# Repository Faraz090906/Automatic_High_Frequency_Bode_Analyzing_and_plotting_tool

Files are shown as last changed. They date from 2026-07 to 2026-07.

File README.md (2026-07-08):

# 📈 Automatic High-Frequency Bode Analyzer & Plotter (AHFBAAPT)

**A standalone, embedded Bode plotter for ~₹8,000 — no PC, no software, just power and a DUT.**

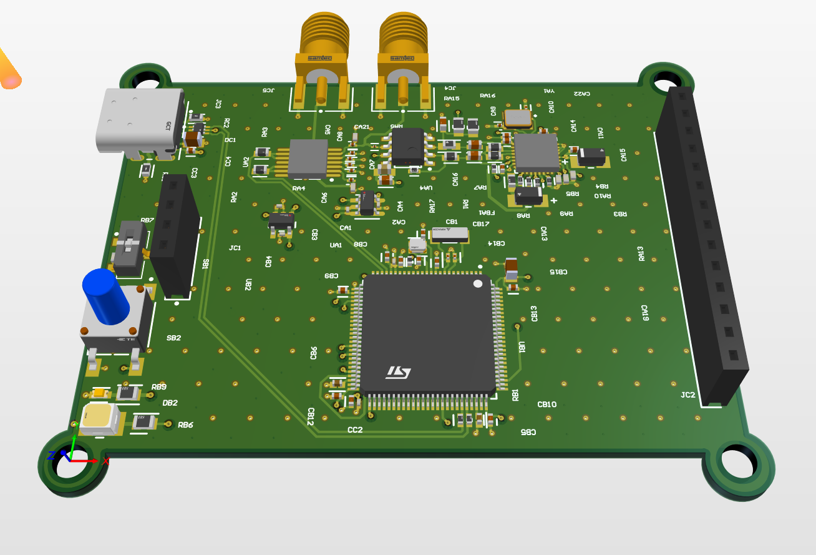
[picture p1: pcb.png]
Bode Plotter PCB








---

## 🔎 Overview

Frequency response analysis usually means choosing between a lab-grade VNA (₹20k–₹2L), a bench scope + signal generator setup (slow and manual), or a PC-tethered NanoVNA. **AHFBAAPT** is a self-contained alternative: a hand-solderable, USB-C powered PCB that sweeps a signal through a device under test (DUT), measures magnitude and phase in real time, displays the result on an onboard touchscreen, and logs everything to a microSD card as CSV — with no computer required.

It's aimed at embedded engineers doing hardware bring-up, university labs teaching signals/RF courses, and hobbyists characterizing filters, inductors, and antenna matching networks.

## ✨ Key Features

- 📡 **Wide sweep range** — 10mHz to 100MHz, with 0.058Hz frequency resolution (32-bit tuning word)
- 🎯 **Accurate measurement** — ±30dB magnitude (±0.5dB accuracy) and 0°–180° phase (±1° accuracy)
- 🔢 **Up to 4096 log-spaced sweep points** per run
- 🔌 **Standalone operation** — no PC or companion software needed
- 🖥️ **2.4" touchscreen TFT** for real-time plotting and read-off of frequency/gain/phase at any point
- 💾 **microSD logging** — sweep results exported as CSV
- ⚡ **USB-C powered** (~300mA) and **USB-C data** for streaming/firmware updates
- 🛠️ **Open firmware** — full STM32 HAL access, easily extended (custom sweep profiles, Wi-Fi, USB streaming)
- 🧩 **Hand-solderable** 4-layer PCB build

## ⚙️ How It Works

The signal chain is a simple stimulus → measure → process pipeline:

1. **Stimulus** — The `AD9913` DDS synthesizer generates a swept sine wave from `f_start` to `f_stop` in log-spaced steps, driven by a 32-bit frequency tuning word.
2. **Measurement** — The `AD8302` gain/phase detector compares the DUT's output against the input and outputs two calibrated DC voltages: `VMAG` (30mV/dB) and `VPHS` (10mV/°).
3. **Processing** — The `STM32H750` reads both channels through its 12-bit ADC with 64× oversampling, converts the readings to dB/° (0.027dB/LSB), and updates the display and log in real time.

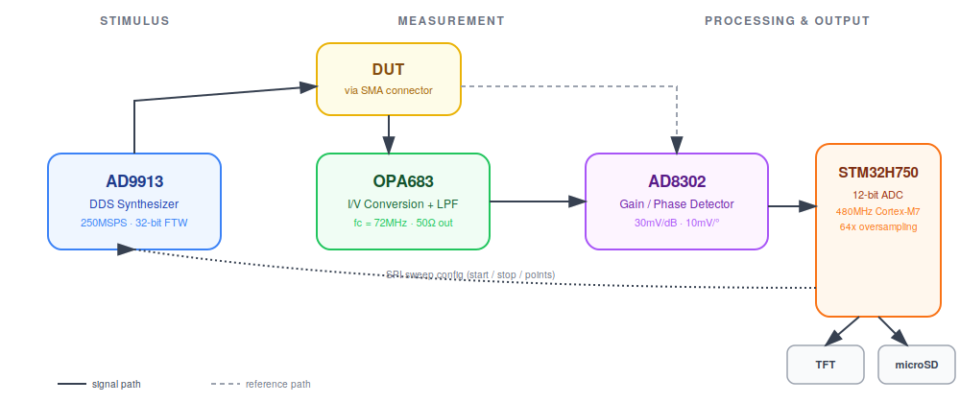
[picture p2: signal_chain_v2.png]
Signal Chain Diagram


## 📊 System Specifications

| Parameter | Value |
|---|---|
| Frequency range | 10mHz – 100MHz |
| Frequency resolution | 0.058Hz (32-bit FTW) |
| Magnitude range | ±30dB (60dB total) |
| Magnitude accuracy | ±0.5dB |
| Phase range | 0° – 180° |
| Phase accuracy | ±1° |
| Sweep points | Up to 4096 (log-spaced) |
| Input impedance | 50Ω (SMA) |
| Display | 2.4" TFT, touch (ILI9341) |
| Storage | microSD, CSV export |
| Connectivity | USB-C (power + full-speed data) |
| Power | USB-C +5V, ~300mA |
| PCB | 4-layer, hand-solderable |

## 🧠 Key Components

| Chip | Role | Highlights |
|---|---|---|
| **AD9913BCPZ** | DDS Synthesizer | 250MSPS, 32-bit FTW, 10mHz–100MHz output, built-in linear sweep, SPI interface |
| **AD8302ARUZ** | Gain/Phase Detector | DC–2.7GHz input, ±30dB magnitude, 0°–180° phase, 30mV/dB & 10mV/°, single 5V supply |
| **OPA683ID** | High-Speed Op-Amp | I/V conversion (TIA), 72MHz low-pass filter, 50Ω output conditioning |
| **STM32H750VBT6** | MCU | 480MHz Cortex-M7, 12-bit ADC (64× oversample), 4× SPI (DDS/TFT/SD/touch), USB-C |

## 🔋 Power Architecture

Two regulated rails are derived from the USB-C +5V input:

- **TLV75533 → 3.3V digital** — powers the STM32, TFT, SD card, and USB
- **TLV75518 → 1.8V analog** — powers the AD9913 and AD8302
- A ferrite bead isolates the analog supply (VDDA) for a clean ADC reference, with separate ground pour planes and a star-point GND to keep digital switching noise off the analog rail

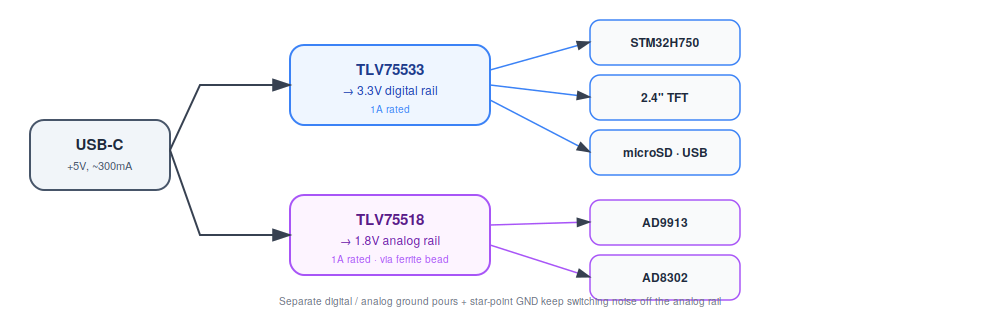
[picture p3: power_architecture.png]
Power Architecture Diagram


## 💰 Cost Breakdown (single unit, approx.)

| Item | Cost (₹) |
|---|---|
| STM32H750VBT6 | 665.71 |
| AD9913BCPZ (DDS) | 2,722.15 |
| AD8302ARUZ | 3,112.06 |
| OPA683ID | 468.96 |
| 2.4" TFT + ILI9341 | 500 |
| LDOs, passives, connectors | ≈500 |
| Crystal, etc. | 300 |
| **Total (all-in)** | **~₹8,270** |

For comparison, a comparable lab-grade VNA costs ₹20,000 – ₹13,00,000.

## 📁 Repository Contents

```
.
├── README.md                     # This file
├── pcb.png                       # Rendered/photographed PCB
├── diagrams/                     # Illustrative diagrams used in this README
│   ├── signal_chain_v2.png
│   └── power_architecture.png
├── pitch.pdf                     # Project pitch deck (problem, use cases, USPs, roadmap)
├── Report.pdf                    # One-page technical summary / spec sheet
├── Schematic.pdf                 # Exported schematic
└── bode_plotter_project.zip      # Full Altium Designer project
    └── Automatic High Frequency Bode Analysing and Plotting Tool (AHFBAAPT)/
        ├── *.PrjPcb, *.PrjPcbStructure   # Altium project files
        ├── schematic_A.SchDoc            # Schematics (split across A/B/C sheets)
        ├── schematic_B.SchDoc
        ├── schematic_C.SchDoc
        ├── PCB1.PcbDoc                    # PCB layout
        ├── *.OutJob                       # Output job configurations (Gerbers, BOM, etc.)
        ├── *.BomDoc                       # Bill of materials
        └── CAMtastic*.Cam                 # CAM/Gerber outputs
```

> **Note:** The hardware design lives entirely in [Altium Designer](https://www.altium.com/) project files (`.PrjPcb`, `.SchDoc`, `.PcbDoc`). You'll need Altium Designer (or Altium 365 viewer) to open and edit them.

## 🚀 Getting Started

### Viewing the Design
1. Download and extract `bode_plotter_project.zip`.
2. Open `Automatic High Frequency Bode Analysing and Plotting Tool (AHFBAAPT).PrjPcb` in Altium Designer to browse schematics and PCB layout.
3. Alternatively, view `Schematic.pdf` and `Report.pdf` directly for a quick look without any EDA tool installed.

### Manufacturing
- Generate Gerbers/CAM outputs via the included `.OutJob` files, or use the pre-generated `CAMtastic*.Cam` files.
- The BOM is available in the `.BomDoc` file inside the project folder.
- Board is a 4-layer design intended to be hand-solderable.

### Powering & Operating (once assembled)
1. Connect the DUT to the SMA input.
2. Power the board via USB-C (+5V, ~300mA).
3. Configure the sweep (start/stop frequency, number of points) via the touchscreen.
4. View magnitude/phase in real time on the 2.4" TFT, and optionally log results to microSD as CSV.

## 👥 Who Is This For?

- **Embedded engineers** — test filters and amplifiers during hardware bring-up without leaving the bench
- **University labs** — an affordable, student-buildable teaching tool for signals/RF courses
- **RF hobbyists** — characterize hand-wound inductors, ceramic filters, and antenna matching networks

## 🗺️ Roadmap

- **Rev 1.0 (current)** — AD9913 + AD8302 + STM32H750, 2.4" TFT, SD card, USB-C. 10mHz–100MHz, ±30dB, ±1°. ~₹8k all-in.
- **Rev 2.0 (near term)** — Full DUT analysis, extend frequency range up to 1GHz, extend gain range to ±50–60dB. Each revision aims to remain hand-solderable and under ₹10,000 built.

## 🧑‍💻 Authors

- Akshara Sarma Chennubhatla — EE24BTECH11003
- Patnam Shariq Faraz Muhammed — EE24BTECH11049
- Siddhanth Yellanki — EE24BTECH11059

## 📜 License

No license file is currently included in this repository. If you intend to reuse or build on this design, please reach out to the authors to clarify usage terms.

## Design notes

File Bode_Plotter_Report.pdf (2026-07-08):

High-Frequency Bode Plotter
10 mHz–100 MHz • ±30 dB Magnitude • ±1° Phase • Standalone • No PC • Open

Firmware

Akshara Sarma Chennubhatla Patnam Shariq Faraz Muhammed Siddanth Yellanki
EE24BTECH11003 / EE24BTECH11049 / EE24BTECH11059

### 1. Deliverables

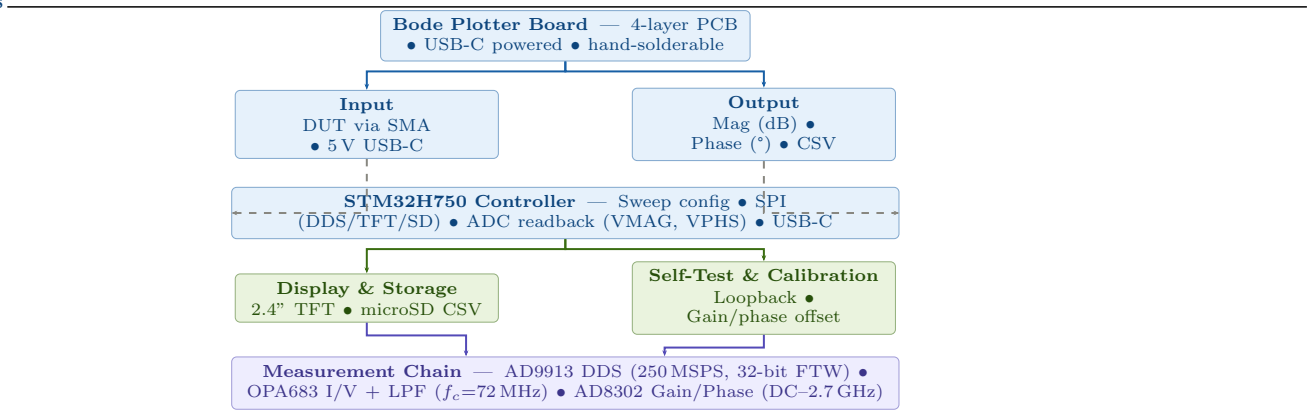
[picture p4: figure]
Bode Plotter Board — 4-layer PCB • USB-C powered • hand-solderable; Input DUT via SMA • 5 V USB-C; Output Mag (dB) • Phase (°) • CSV; Display & Storage 2.4” TFT • microSD CSV; Self-Test & Calibration Loopback •; Gain/phase offset

STM32H750 Controller — Sweep config • SPI (DDS/TFT/SD) • ADC readback (VMAG, VPHS) • USB-C

Measurement Chain — AD9913 DDS (250 MSPS, 32-bit FTW) • OPA683 I/V + LPF (fc=72 MHz) • AD8302 Gain/Phase (DC–2.7 GHz)

### 2. System Specifications

Frequency Range

### 10 mHz – 100 MHz • 0.058 Hz resolution (32-bit FTW) • Up

to 4096 log-spaced sweep points

Magnitude & Phase
Magnitude: ±30 dB range, ±0.5 dB accuracy (30 mV/dB) Phase: 0°–180°, ±1° accuracy (10 mV/°)

Signal Source & ADC
AD9913 DDS, 250 MSPS, 25 MHz TCXO reference STM32H750 480 MHz M7 • 12-bit ADC • 64× oversample • 0.027 dB/LSB

Power
USB-C +5 V, ∼300 mA • 3.3 V digital (TLV75533) • 1.8 V analog (TLV75518) • Ferrite-bead isolated rails

### 4. Interfaces

SPI Bus
AD9913 config • 2.4” TFT (ILI9341) • microSD • touch controller

Analog RF & ADC
IOUT/IOUTB diff. out, 50 Ω DUT port, REF tap to AD8302 VMAG: 30 mV/dB • VPHS: 10 mV/°• RC filter fc=159 Hz

USB-C
Full-speed USB • Power + data • Future: live streaming

### 5. Performance

Key Features
- Fully standalone — no PC, no software
- 4096-point log sweep, touch readout of freq/gain/phase
- Real-time Bode plot on 2.4” TFT display
- microSD CSV export, open STM32 HAL firmware

### 3. Key ICs

AD9913 — DDS Synthesiser
250 MSPS • 10 mHz–100 MHz output • 32-bit FTW (0.058 Hz res.) • Built-in linear sweep • SPI interface

AD8302 — Gain/Phase Detector
DC to 2.7 GHz • ±30 dB magnitude range • 0°–180° phase range
- 30 mV/dB • 10 mV/°• Single 5 V supply

OPA683 — High-Speed Op-Amp
I/V conversion (TIA config) • fc = 72 MHz LPF • 50 Ω output conditioning

STM32H750VBT6 — MCU
480 MHz Cortex-M7 • SPI ×4 (DDS/TFT/SD/touch) • USB-C Full Speed • LQFP-100, hand-solderable

TLV75518 / TLV75533 — LDOs
1.8 V analog rail + 3.3 V digital rail • 1 A rated • Separate pour planes.

### 6. Cost Breakdown

Item | INR
PCB Fabrication | 2,400

PCB Assembly

2,680

Components / BoM | 9,949
Total | 15,029

Further details: Bode Plotter (https://drive.google.com/drive/folders/1nUOeqKWaKO9xSWlELa47L8NvQM5F9w_Q)

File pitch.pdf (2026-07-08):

# Bode Plotter PCB

## Swept Frequency Analyser · 10 mHz to 100 MHz

## 10 mHz

to 100 MHz

±30 dB

Magnitude

±1°

Phase accuracy

˜|8k

All-in cost

EE24BTECH11003: Akshara Sarma · EE24BTECH11049: Faraz P · EE24BTECH11059: Siddhanth

AD9913 DDS · AD8302 · STM32H750VBT6 · March 2026

## The Problem

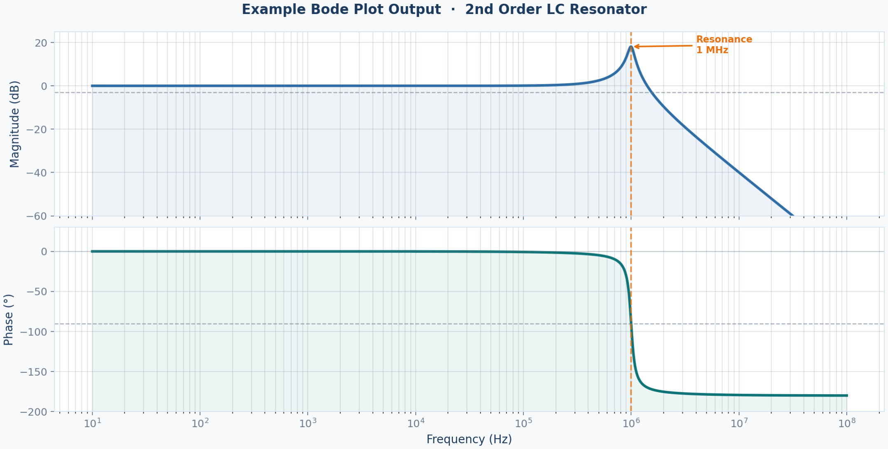
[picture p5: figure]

## Engineers need frequency

response data.

Today’s options:
- Lab VNA — accurate but |20k -|2 Lakhs
- Bench scope + sig gen — slow, manual, error-prone
- NanoVNA — cheap but
PC-tethered, limited range

None are self-contained, affordable & embedded.

USE CASE

A standalone,

# embedded Bode plotter

for |8k.

## Sweep 10 mHz to 100 MHz. Read

magnitude and phase on a 2.4 inch display.

## Log results to SD card. No PC. No

software. Just power and a DUT.

Self-contained

No PC needed

Open firmware

Full STM32 control

Logs to SD

CSV export

˜|8k built

4-layer PCB

## Who Is It For

Embedded Engineers

Test filters and amplifiers during hardware bring-up
without leaving the bench.

University Labs

Affordable teaching tool
for circuits and signals
courses.
Student-buildable.

RF Hobbyists

Characterise hand-wound
inductors, ceramic filters, antenna matching
networks.

## Anyone who needs frequency response data and doesn’t want to

spend |50000 on a VNA.

USE CASE

## How It Works

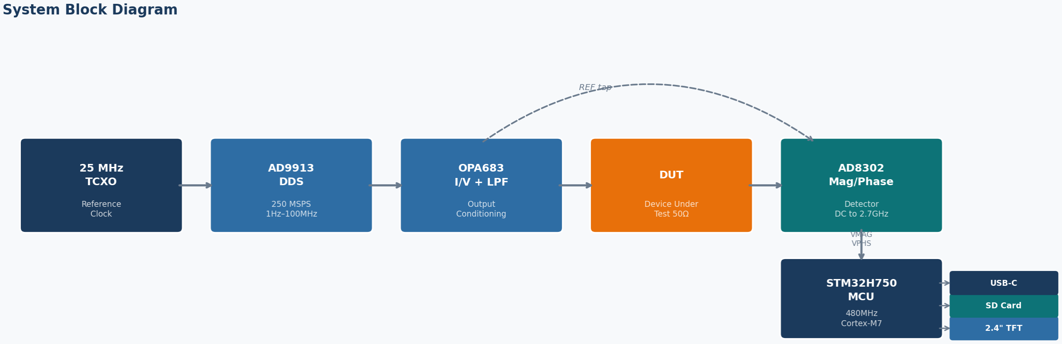
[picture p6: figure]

DDS generates swept sine · AD8302 measures ratio of output to input · STM32 reads two DC voltages and plots the result in real time

HOW IT WORKS

## Signal Chain

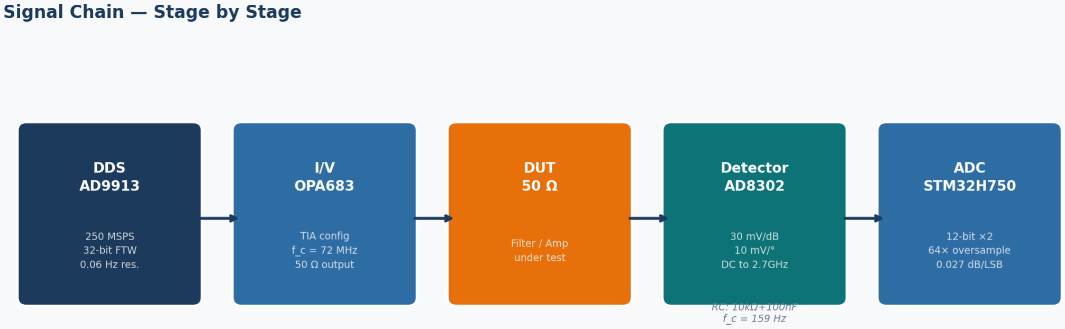
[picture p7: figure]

Stimulus
AD9913 DDS sweeps

from fstart to fstop in
log-spaced steps. 32-bit
tuning word: 0.058 Hz
resolution.

Measurement
AD8302 outputs two
calibrated DC voltages:
VMAG (30 mV/dB) and
VPHS (10 mV/°).

Processing
STM32 ADC reads both
channels with 64x
oversampling, converts to
dB/°, updates the display.

HOW IT WORKS

AD9913

DDS Synthesiser

- 250 MSPS system
clock
- 10 mHz to 100 MHz
output
- 32-bit frequency word
- Built-in linear sweep
mode
- SPI interface

AD8302

Gain/Phase Detector

- DC to 2.7 GHz input
range
- ±30 dB magnitude
range
- 0° to 180° phase
range
- 30 mV/dB · 10 mV/°
output
- Single supply, 5 V

## STM32H750

MCU & Controller

- 480 MHz Cortex-M7
- 12-bit ADC, 64×
oversample
- SPI × 4: DDS, TFT,
SD, touch
- USB-C full speed
- LQFP-100,
hand-solderable

Three chips do all the work.

## Power Architecture

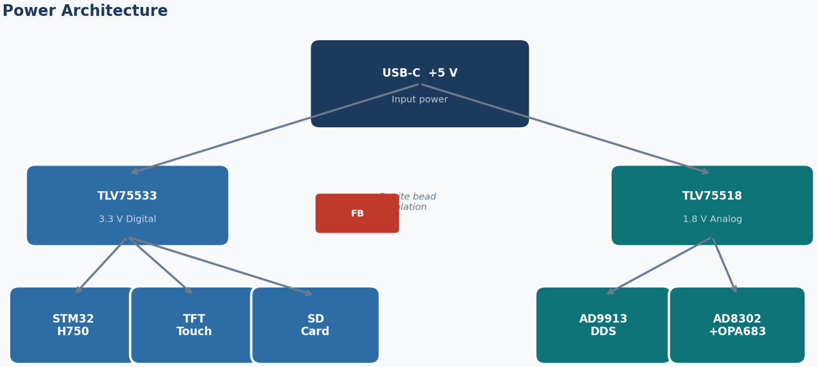
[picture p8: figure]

Both LDOs rated 1 A. Total system current: ˜300 mA at full speed. Powered from any USB-C source.

Two rails from USB-C +5 V:

- TLV75533 → 3.3 V digital

STM32, TFT, SD card, USB

- TLV75518 → 1.8 V analog

AD9913, AD8302

- Ferrite bead isolates VDDA Clean ADC reference, no digital noise on analog rail
- 1.8 V split: analog vs. digital Separate pour planes, star-point GND
HOW IT WORKS

## Unique Selling Points

No PC required
Full sweep, display and SD logging run on the STM32. Results appear on the 2.4 in TFT in real time. Touch screen lets you read off frequency, gain and phase at any point.

Open firmware
STM32H750 | with | full | HAL | access.
Change sweep range, point count, settle time, add USB streaming, add Wi-Fi module — all in C.

### 10 mHz floor

AD9913 32-bit FTW gives 0.06 Hz resolution. Most comparable tools start at 50 kHz or higher.

USP

## Cost Breakdown

Item | Cost
STM32H750VBT6 | |665.71
AD9913BCPZ (DDS) | |2,722.15
AD8302ARUZ | |3,112.06
OPA683ID | |468.96
2.4” TFT + ILI9341 | |500
LDOs, passives, connectors | ≈ |500
crystal, etc. | |300
All-in (single unit) | ˜|8,270

Comparable lab VNA: |20k - 13L This instrument: |8k
COST

## Specifications at a glance

Parameter | Value | Feature | Detail
Frequency range | 10 mHz – 100 MHz | Display | 2.4” TFT, touch
Magnitude range | ±30 dB (60 dB total) | Storage | microSD, CSV
Phase range | 0° – 180° | USB | USB-C Full Speed
Mag. accuracy | ±0.5 dB | Power | USB-C +5 V
Phase accuracy | ±1° | MCU | STM32H750, 480 MHz
Freq. resolution | 0.058 Hz | DDS | AD9913, 250 MSPS
Sweep points | Up to 4096 | Detector | AD8302, DC–2.7 GHz
Input impedance | 50 Ω | Build | Hand-solderable

## Roadmap

Rev 1.0 — Now

AD9913 + AD8302 + STM32H750 2.4” TFT · SD card · USB-C 10 mHz–100 MHz · ±30 dB · ±1°

|8k all-in

Rev 2.0 — Near Term

Provide complete DUT analysis Increase freq range upto 1GHz Increase gain range upto ± 50dB-60dB

Each revision remains hand-solderable and under |10000 built.

NEXT STEPS

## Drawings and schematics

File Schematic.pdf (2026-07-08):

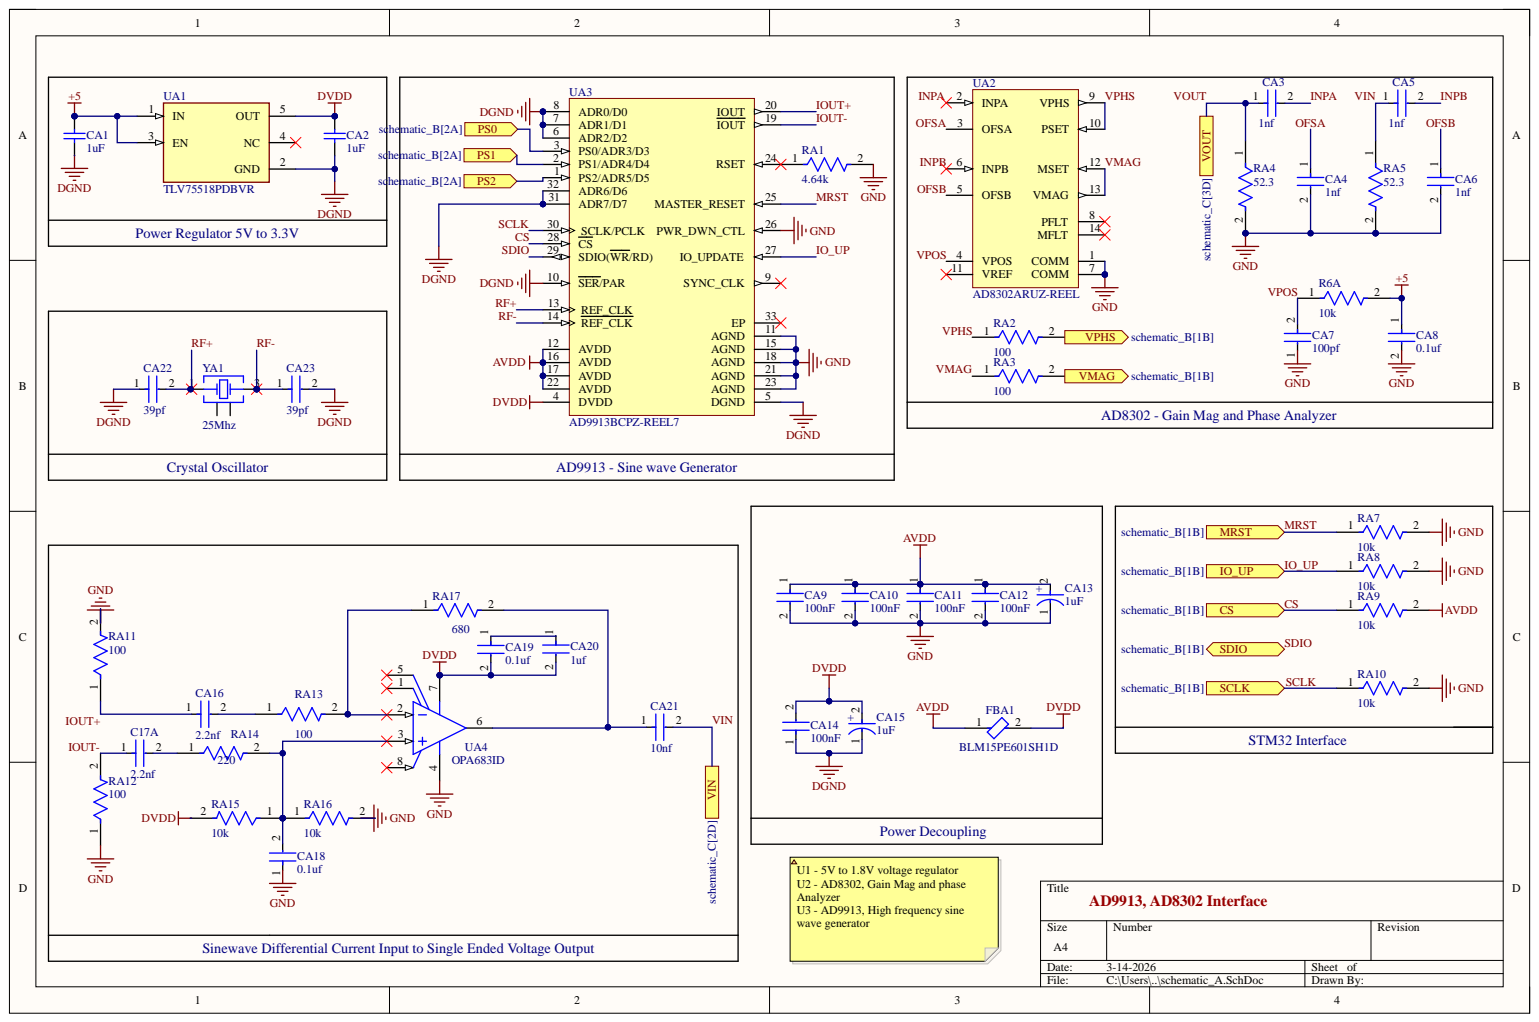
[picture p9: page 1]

AD8302 - Gain Mag and Phase Analyzer

U1 - 5V to 1.8V voltage regulator
U2 - AD8302, Gain Mag and phase
Analyzer
U3 - AD9913, High frequency sine
wave generator

Sinewave Differential Current Input to Single Ended Voltage Output

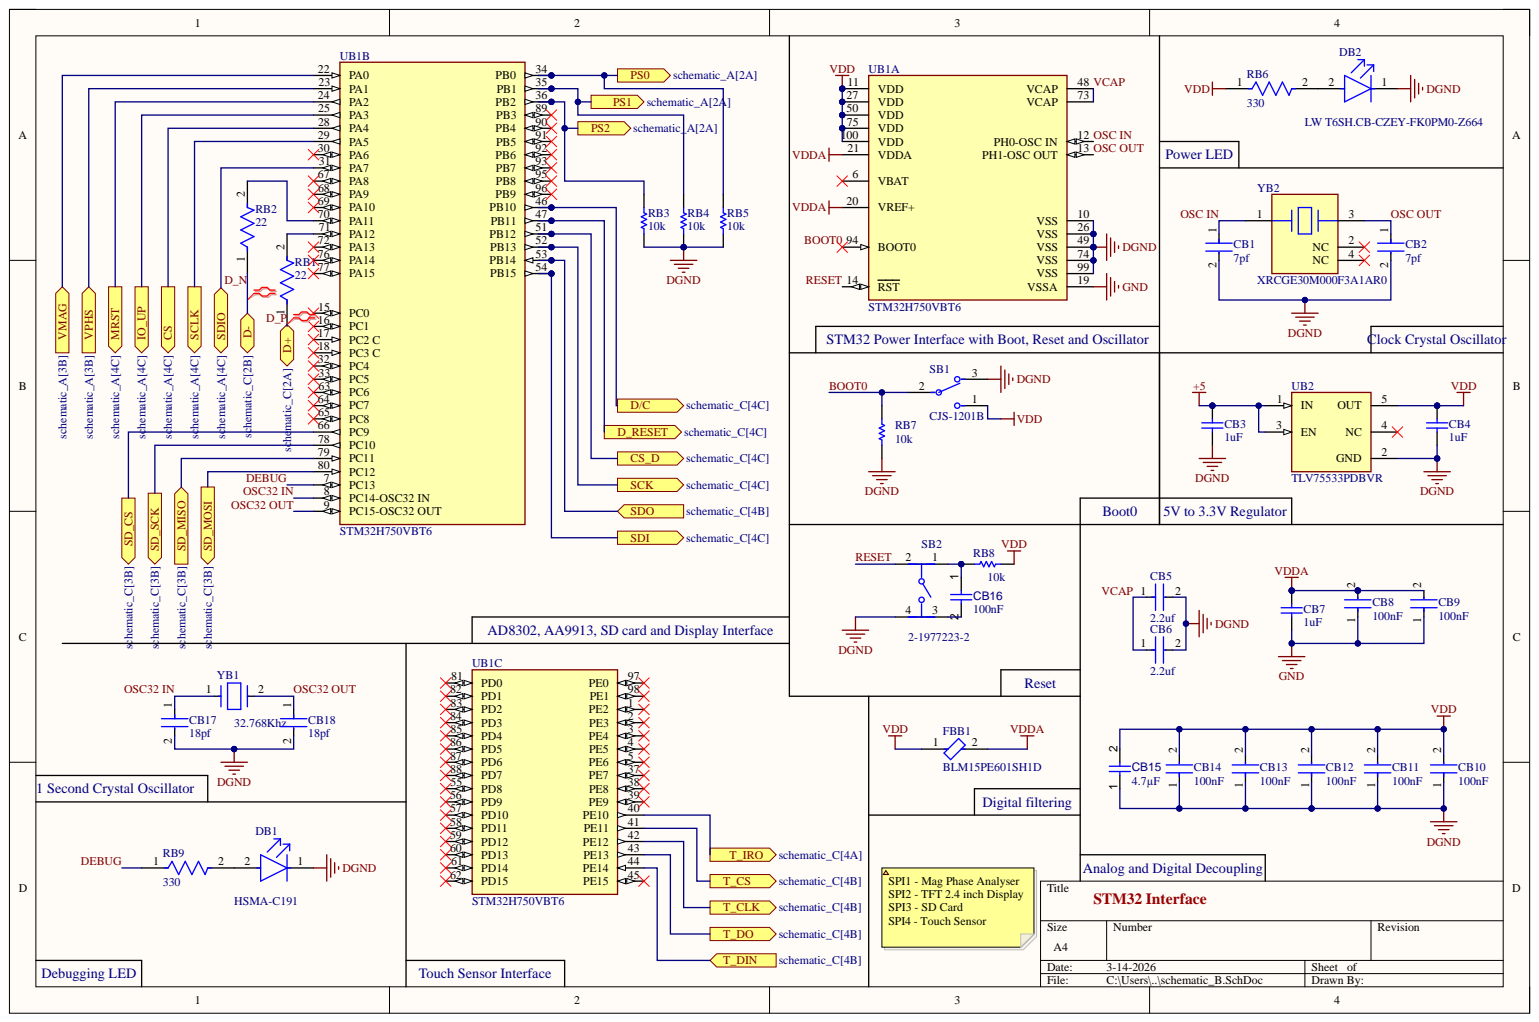
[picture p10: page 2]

STM32 Power Interface with Boot, Reset and Oscillator

PC10 78
PC11 79
PC12 80

DEBUG | PC13 7

AD8302, AA9913, SD card and Display Interface

Analog and Digital Decoupling

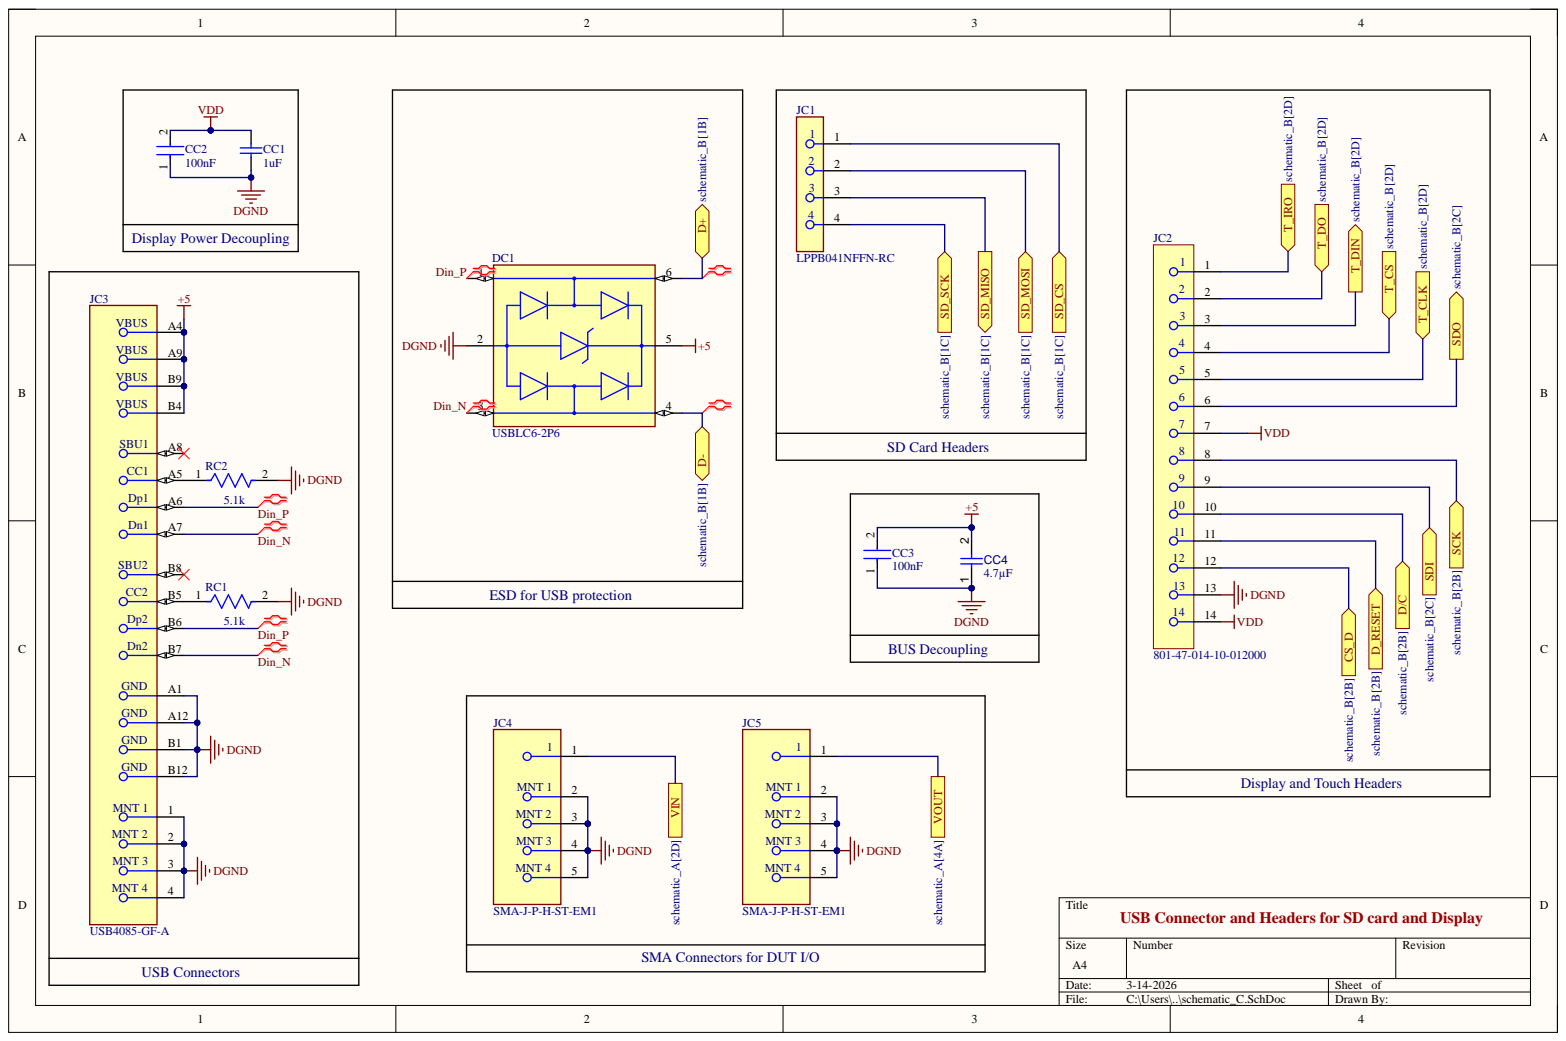
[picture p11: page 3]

ESD for USB protection

USB Connector and Headers for SD card and Display

SMA Connectors for DUT I/O
